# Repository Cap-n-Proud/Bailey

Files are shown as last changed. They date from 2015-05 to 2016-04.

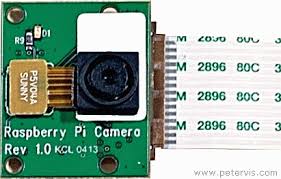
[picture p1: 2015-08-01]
hardware/Img/images.jpg

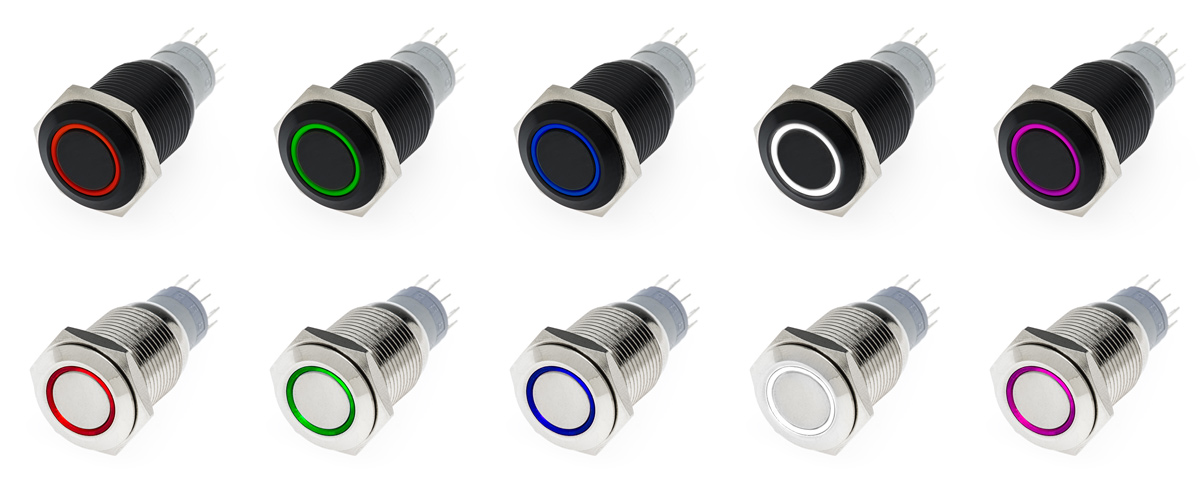
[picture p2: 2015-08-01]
hardware/Img/led-push-button-switch-color-options-pb-x-spdt-x.jpg

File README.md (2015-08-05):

Bailey
======

Areas of research:
1. AI: neural networks and SPO to improve stability
2. Computer vision potentially with neural network
3. Odometry
4. 
To log a warning when anrduino receives an unkown command
see why it makes "waves" when advancing forward
verify bug when hit refresh button robot stalls... (maybre because of long delay in passing telemetry headers?
change PID config only when needd to save time

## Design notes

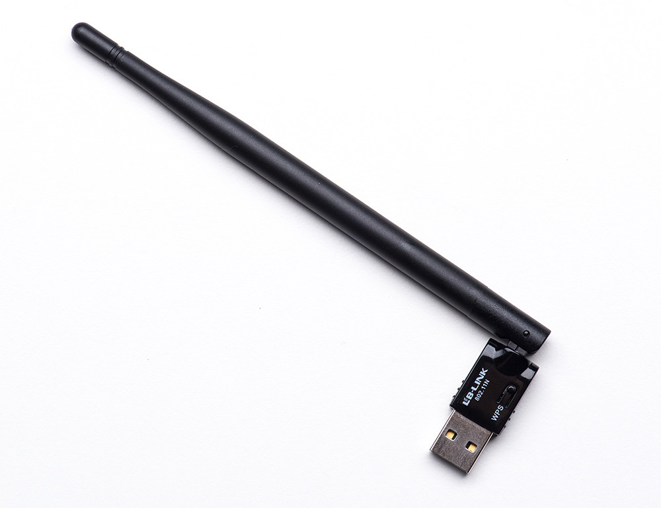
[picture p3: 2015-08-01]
hardware/Img/lrg_wifi_antenna_1.jpeg

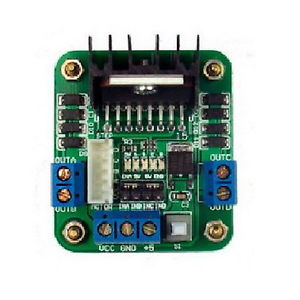
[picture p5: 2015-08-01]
hardware/Img/$_35.JPG

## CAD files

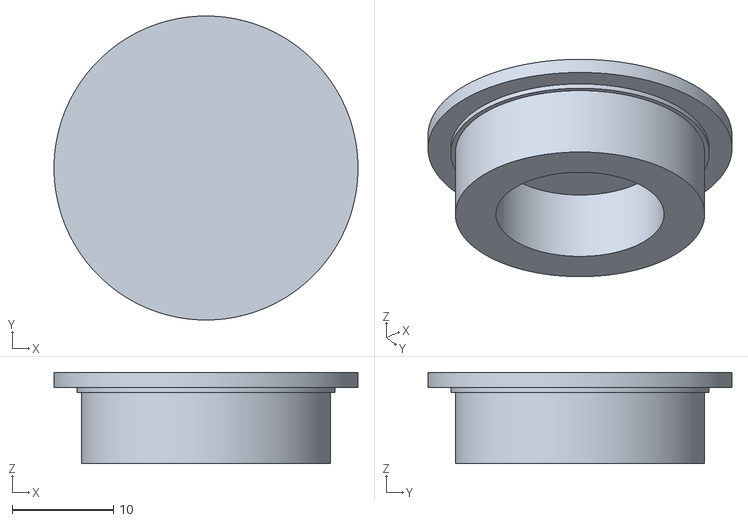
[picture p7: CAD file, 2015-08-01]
hardware/SupportNOservo.stl
30.0 x 30.0 x 9.00

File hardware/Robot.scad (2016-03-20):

//Make passage for cables larger
RobotY = 220;
RobotX = 80;
RobotZ = 5;
BodyHoleR = 20;
BodyHoleSpace = 55;

plateX = 150;
plateZ = 3;
plateY = RobotX;
cablePassageWidht = 8;
plateanchorX = RobotZ;
plateanchorY = 15;
holeradius = 3;
holespace = 3 * holeradius;
borderZ = 30;
border = 8;
T = 0.3;
$fs = 0.01;

stepperSupportHeight = 70;

border = holespace + ((plateX) / holespace - floor((plateX) / holespace)) / 2;
include < TextGenerator.scad > ;

module put_pilogo(mt) {
    fn = "raspberrypi_logo.dxf";
    // calculate the scale and which offset to use

    linear_extrude(height = mt) import (file = fn, scale = scx);
}


module put_Alogo(mt) {
    fn = "arduino.dxf";
    // calculate the scale and which offset to use

    linear_extrude(height = mt) import (file = fn, scale = scx);
}

module put_OAlogo(mt) {
    fn = "ohw-logo.dxf";
    // calculate the scale and which offset to use    
    linear_extrude(height = mt) import (file = fn, scale = scx);
}


module SUB_batteryAnchor() {

}

module arduinoLogo(h, r) {

    scale([0.9, .7, 1]) union() {
        difference() {
            cylinder(h = h, r = r);
            cylinder(h = h, r = r - .25 * r);
        }
        translate([1.8 * r, 0, 0]) difference() {
            cylinder(h = h, r = r);
            cylinder(h = h, r = r - .25 * r);
        }

    }
    translate([0, 0, h / 2]) cube([0.6 * r, 0.2 * r, h], center = true);
    translate([2 * r - 0.4 * r, 0, h / 2]) {
        cube([0.6 * r, 0.2 * r, h], center = true);
        rotate([0, 0, 90]) cube([0.6 * r, 0.2 * r, h], center = true);
    }
}

module plate(plateX, plateY, plateZ, borderZ, holes, baseF, baseB, text) {
    difference() {
        linear_extrude(plateZ, center = true, convexity = 0, twist = 0)

        difference() {

            union() {
                square([plateX, plateY], center = true);

                translate([-plateX / 2 - plateanchorX, plateanchorY + RobotX / 8 - (7 * (RobotX / 8) - plateanchorY), 0]) square([plateanchorX, plateanchorY], center = "True");

                mirror([0, 1, 0]) translate([-plateX / 2 - plateanchorX, plateanchorY + RobotX / 8 - (7 * (RobotX / 8) - plateanchorY), 0]) square([plateanchorX, plateanchorY], center = "True");


                translate([+plateX / 2, plateanchorY + RobotX / 8 - (7 * (RobotX / 8) - plateanchorY), 0]) square([plateanchorX, plateanchorY], center = "True");
                mirror([0, 1, 0]) translate([+plateX / 2, plateanchorY + RobotX / 8 - (7 * (RobotX / 8) - plateanchorY), 0]) square([plateanchorX, plateanchorY], center = "True");

            }

            //punchholes at the bottom of the plate
            if (holes == "True") {
                for (j = [border: holespace: plateY - border]) {
                    for (i = [border: holespace: plateX - 2 * border]) {
                        translate([i + border - plateX / 2 - holeradius / 2, j - plateY / 2, 0]) circle(holeradius);
                    }
                }

            }
        }

        //Passage for cables
        translate([-plateX / 2 + cablePassageWidht, j + border - plateY / 2, 0]) cube([cablePassageWidht, 0.5 * plateY, plateZ], center = true);
        translate([plateX / 2 - cablePassageWidht, j + border - plateY / 2, 0]) cube([cablePassageWidht, 0.5 * plateY, plateZ], center = true);

    }
    if (baseF == "True")
        translate([-plateX / 2, plateY / 2 - plateZ, -plateZ / 2]) cube([plateX, plateZ, borderZ]);
    if (baseB == "True")
        translate([-plateX / 2, -plateY / 2, -plateZ / 2]) cube([plateX, plateZ, borderZ]);

    translate([-plateX / 2, -plateY / 2, 5]) rotate(90, [1, 0, 0]) scale([2, 2, 1]) drawtext(text);

}

module SensorsPlate() {
    IRLedD = 3;

    plate(plateX, plateY, plateZ, borderZ, "True", "True", "false", "");
    difference() {
        translate([0, -plateY / 2 + 10, borderZ - plateZ / 2])
        rotate([180, 0, 0]) difference() {
                scale(v = [1, 0.30, 1]) difference() {
                    cylinder(r = plateX / 2, h = borderZ, center = false);
                    cylinder(r = plateX / 2 - 2 * plateZ, h = borderZ, center = false);
                }


                translate([-plateX / 2, -plateY / 2 + 10, 0]) cube([plateX, 0.35 * plateX / 2, plateY / 2]);
            }
            //hole for the IR sensor
        translate([-plateX / 2 + 12, -plateY / 2 + 2, borderZ / 4]) rotate([100, 0, -30]) translate([6, -3.48, 0]) cube([6, 6.95, 10]);
        translate([-8, -plateY / 2 - 10, borderZ / 4]) rotate([100, 0, 0]) translate([6, -3.48, 0]) cube([6, 6.95, 10]);
        translate([+plateX / 2 - 12, -plateY / 2 + 2, borderZ / 4]) rotate([100, 0, 30]) translate([-12, -3.48, 0]) cube([6, 6.95, 10]);

        //holes for sonars and slots for sensors
        translate([0 + 28, -plateY / 2 - 8, borderZ / 2]) rotate([90, 0, 0]) cylinder(r = 16.8 / 2, h = 8);
        translate([0 - 28, -plateY / 2 - 8, borderZ / 2]) rotate([90, 0, 0]) cylinder(r = 16.8 / 2, h = 8);
        translate([0, -plateY / 2 - 8, borderZ / 2]) rotate([90, 0, 0]) cube([3, 1, 5]);
        translate([-plateX / 2 + 12, -plateY / 2 + 2, borderZ / 2]) rotate([90, 0, -30]) cube([3, 1, 5]);
        translate([+plateX / 2 - 12, -plateY / 2 + 2, borderZ / 2]) rotate([90, 0, 30]) cube([3, 1, 5]);

        translate([-plateX / 2 + 12, -plateY / 2 + 2, borderZ / 4]) rotate([100, 0, -30]) cylinder(r = 1.5 + IRLedD, h = 10);
        translate([-8, -plateY / 2 - 10, borderZ / 4]) rotate([100, 0, 0]) cylinder(r = 1.5 + IRLedD, h = 10);
        translate([+plateX / 2 - 12, -plateY / 2 + 2, borderZ / 4]) rotate([100, 0, 30]) cylinder(r = 1.5 + IRLedD, h = 10);
    }

    //Tubes to focus the IR beams
    translate([-plateX / 2, -plateY / 2 - 30, 0]) difference() {
        cylinder(r = 1 + IRLedD, h = 15);
        cylinder(r = IRLedD, h = 15);
    }
    translate([-plateX / 2 + 15, -plateY / 2 - 30, 0]) difference() {
        cylinder(r = 1 + IRLedD, h = 15);
        cylinder(r = IRLedD, h = 15);
    }
    translate([-plateX / 2 + 30, -plateY / 2 - 30, 0]) difference() {
            cylinder(r = 1 + IRLedD, h = 15);
            cylinder(r = IRLedD, h = 15);
        }
        //	translate([-8,-plateY/2-10,borderZ/4]) rotate([100,0,0])difference (){cylinder(r=1.2*IRLedD,h=8); cylinder(r=IRLedD,h=10);}
        //	translate([+plateX/2-12,-plateY/2+2,borderZ/4]) rotate([100,0,30])difference (){cylinder(r=1.2*IRLedD,h=10); cylinder(r=IRLedD,h=8);}
}

module Powerplate() {

    difference() {
        plate(plateX, plateY, plateZ, borderZ, "True", "True", "True", "Power");
        //fix for batteries
        translate([plateX / 2 - 15, plateY / 2 + 5, borderZ / 2]) translate([0, 0, 3]) rotate([90, 0, 0]) cylinder(h = 10, r = 2);
        translate([-plateX / 2 + 15, plateY / 2 + 5, borderZ / 2]) translate([0, 0, 3]) rotate([90, 0, 0]) cylinder(h = 10, r = 2);
        translate([plateX / 2 - 15, -plateY / 2 + 5, borderZ / 2]) translate([0, 0, 3]) rotate([90, 0, 0]) cylinder(h = 10, r = 2);
        translate([-plateX / 2 + 15, -plateY / 2 + 5, borderZ / 2]) translate([0, 0, 3]) rotate([90, 0, 0]) cylinder(h = 10, r = 2);

    }

    translate([plateX / 2 - 15, plateY / 2 + 4, borderZ / 2])
    difference() {
        sphere(2);
        rotate([0, 90, 0]) translate([0.7, 0.6, 0]) cylinder(h = 10, r = 1.1, center = true);
    }
    translate([-plateX / 2 + 15, plateY / 2 + 4, borderZ / 2])
    difference() {
        sphere(2);
        rotate([0, 90, 0]) translate([0.7, 0.6, 0]) cylinder(h = 10, r = 1.1, center = true);
    }
    translate([plateX / 2 - 15, -plateY / 2 - 1, borderZ / 2]) rotate([0, 0, 180])
    difference() {
        sphere(2);
        rotate([0, 90, 0]) translate([0.7, 0.6, 0]) cylinder(h = 10, r = 1.1, center = true);
    }
    translate([-plateX / 2 + 15, -plateY / 2 - 1, borderZ / 2]) rotate([0, 0, 180])
    difference() {
        sphere(2);
        rotate([0, 90, 0]) translate([0.7, 0.6, 0]) cylinder(h = 10, r = 1.1, center = true);
    }


    //mid section
    difference() {
        translate([-plateX / 2, 0, 0]) cube([plateX, plateZ, borderZ]);
        for (i = [1: plateX / 4: plateX]) {
            translate([i + (-plateX / 2) + borderZ / 2, 10, borderZ / 2]) rotate([90, 0, 0]) cylinder(20, r = 0.8 * borderZ / 2);

        }


    }


}

module BrainPlate() {
    plate(plateX, plateY, plateZ, borderZ, "False", "True", "True", "");
    translate([-plateX / 2, -plateY / 2, borderZ / 2]) {
        color("green") rotate([90, 0, 0])
        translate([120, -2, 0]) scale(0.3) arduinoLogo(5, 30);
        translate([5, -12, 0]) scale(0.1) put_pilogo(1.5 / 0.1);
        translate([80, -2, 0]) scale(0.1) put_OAlogo(1.5 / 0.1);
    }
}
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

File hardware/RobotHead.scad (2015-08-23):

//Increase shell thickness
//Change slot for Raspberry 
//Change slot for camera (no need of pan

PIcameraDiam = 8;
PIcameraX = 25;
PIcameraY = 25;
// Raspberry Pi dimensions 85.60mm x 56mm x 21mm 
widht = 148;
depth = 120;
border = widht * 0.2;
T = 6;
2DOF_L = 40;
2DOF_H = 45;
USBH = 20;
USBL = 50 + 6;
FN = 50;
CameraModulePos = [0, 70, 20];
Tolerance= 0.5;
HSupportHoleDiam = 25;

$fn = 150;

//$fs = 0.01; // change me to 0.5 when doing final render for export

phi = 1.618033988749894848204586834;

//-----------------------------------
module HeadShell() {
	difference() {
		resize([widht + border, depth, depth]) sphere(1);
		//Create the inner shell
		resize([widht + border - T, depth - T, depth - T]) sphere(1);
	}
	//Endcaps
	intersection() {
		resize([widht + border, depth, depth ]) sphere(1);
		translate([widht / 2 - 3 / 2, 0, 0]) cube([3, 100, 100], center = true);

	}
	intersection() {
		resize([widht + border, depth, depth]) sphere(1);
		translate([-widht / 2 + 3 / 2, 0, 0]) cube([3, 100, 100], center = true);

	}
}
module H() {
	difference() {
		HeadShell();
		//2DOF slot
		translate(CameraModulePos) rotate([100, 0, 0]) resize([2DOF_L, 2DOF_H, 50]) cylinder(h = 30, r = 100);

		//Two cubes to cut the ends of the head
		translate([widht / 2, -widht / 2, -widht / 2]) cube(widht);
		translate([-3 / 2 * widht, -widht / 2, -widht / 2]) cube(widht);
		//Lower cut
		translate([-widht / 2, -widht / 2, -(widht + 40)]) cube(widht);
		//Holes for buttons
		translate([-widht / 4, -depth / 4, widht / 4]) rotate([45, 30, -45]) ButtonHoleL();
		translate([+widht / 4, -depth / 4, widht / 4]) rotate([45, 30, 0]) ButtonHoleL();

		//Raspberrry slot
		translate([-USBL / 2, -depth / 2, -10]) cube([USBL, 20, USBH]);
 
        translate([-1.1*USBL / 2, -depth / 2, -10]) cube([1.1*USBL, 20, 3 ]);
		//Simulates Raspberry PI dimensions
		//translate([-USBL/2+56,-depth/2,-10])rotate([0,0,90])cube([85.60,56,21]);
        
        //Hole for RGB LED
        translate([0, 0, depth/2]) rotate([0, 0, 0]) cylinder(h=10,r=5/2-Tolerance, center=true);
        
        //Hole for anchoring
		translate([widht / 2, 0, 0]) rotate([90, 180, 90]) cylinder(h=10,r=HSupportHoleDiam/2, center=true);
		//Microserv slot
        translate([-widht / 2 - 10, 0, 0]) rotate([90, 180, 90]) translate([-5.9 - 4.7 / 2, 0, 0]) microservo();

	}
    
    //This is the support fo  rthe raspberry slot
     intersection(){
            HeadShell();
            for (z = [-USBL/2: 2: USBL/2]) 
            {
                translate([z, -depth/2+1, 0])
                cube([0.4,20,USBH], center = true);
            }
            }
		
}
//-----------------------------------

module camera_supportOLD()

{
	translate(CameraModulePos - [0, +5, +6] - [0, 0, T + 12]) rotate([0, 0, 00]) box(13, 24.5, 17, 3);
	difference() {
		translate(CameraModulePos - [0, 0, T + 12]) box(2DOF_L + 2 * T, 2DOF_H, 30, T);

		difference() {
			translate(CameraModulePos - [0, 0, T + 12]) box(2DOF_L + 2 * T, 2DOF_H, 30, T);
			resize([widht + border - T, depth - T, depth - T]) sphere(1, $fn = FN);

		}
	}

}
//-----------------------------------

module box(Xdim, Ydim, Zdim, thickness)
//Creates a box, dimensions are internal
{
	difference() {
		//translate([10,0,-thickness])
		cube([Xdim + thickness, Ydim + thickness, Zdim], center = true);
		translate([0, 0, thickness / 2]) cube([Xdim, Ydim, Zdim], center = true);

		translate([-Xdim / 2, 0, -0.5 * Zdim]) cube([5, Ydim + 2 * thickness, Zdim / 2 + thickness], center = true);
		translate([+Xdim / 2, 0, -0.5 * Zdim]) cube([5, Ydim + 2 * thickness, Zdim / 2 + thickness], center = true);
		translate([+Xdim / 2, 0, 0]) cube([thickness / 2, 0.3 * Ydim, Zdim], center = true);
		translate([-Xdim / 2, 0, 0]) cube([thickness / 2, 0.3 * Ydim, Zdim], center = true);

	}
}

module support() {
	difference() {

		linear_extrude(height = 4, center = true, convexity = 10, twist = 0) polygon(points = [
			[0, 0],
			[0, 16],
			[4, 16]
		]);
		translate([2, 18, 0]) rotate([90, 0, 0]) cylinder(h = 15, d = 1.5);
		translate([0.5, 10, -6]) cube([4, 2, 12], center = false);
	}
}


//-----------------------------------

module CS()
translate(CameraModulePos + [6.25, -25, -32]) {
	box(24.5, 13, 17, T);
	translate([0, 12, 0]) cube([24.5 + T, 5 + T, 17], center = true);
}
//-----------------------------------



module camera_support()

{

	difference() {
		CS();

		difference() {
			CS();
			resize([widht + border - T, depth - T, depth - T]) sphere(1);

		}
	}

}

module ButtonHoleL() {

	cylinder(h = 20, r = 8);
}


module TiltServo() {
	//translate([widht/2-10,0,0])rotate([90,90,90])translate([-35.1,0,0])TiltServo();
	translate([0, -5, 0]) cylinder(h = 20, r = 2.5);
	translate([0, 5, 0]) cylinder(h = 20, r = 2.5);

	translate([50.5, -5, 0]) cylinder(h = 20, r = 2.5);
	translate([50.5, 5, 0]) cylinder(h = 20, r = 2.5);

	translate([35.1, 0, 0]) cylinder(h = 40, r = 5);
	translate([35.1, 0, 0]) cylinder(h = 20, r = 5);

	translate([5, -10.5, 0]) cube([41.50, 21, 20], center = false);
}






module SUB_bearing() {
	cylinder(h = 0.5, r = 25.5 / 2);
	translate([0, 0, 0.5]) cylinder(h = 1.5, r = 30 / 2);
}

module bearingServo() {
	difference() {
		SUB_bearing();
		cylinder(h = 5, r = 2);
	}
}

module bearingNoServo() {
	union() {
		SUB_bearing();
        
		translate([0,0,-8/2])difference(){
            cylinder(h = 12, r = HSupportHoleDiam/2-Tolerance, center=true);
            cylinder(h = 12, r = HSupportHoleDiam/2-Tolerance-4, center=true);
        }
	}
}



module microservo() {

	translate([0, 0, 0]) cylinder(h = 20, r = 1.2);
	translate([27.2, 0, 0]) cylinder(h = 20, r = 1.2);

	translate([5.9 + 4.7 / 2 + 6, 0, 0]) cylinder(h = 40, r = 7 / 2);

	translate([5.9 + 4.7 / 2, 0, 0]) cylinder(h = 40, r = 7);
}

/*difference(){
translate([-5,-10,-0])cube([40,20,2]);
microservo();
}*/


//camera_support();

/*difference(){
translate([-5,-10,0])cube([35,20,1], center=false);
microservo();
}*/

module PiSupport() {
	difference() {

		translate([-USBL / 2, -widht / 2, -USBH / 2 - 5]) cube([USBL, widht, 5]);
		translate([0, 0, -USBH / 2 - 2.5]) cube([USBL - 20, 100, 5], center = true);

		difference() {
			translate([-USBL / 2, -widht / 2, -USBH / 2 - 5]) cube([USBL, widht, 5]);
			resize([widht + border - T, depth - T, depth - T]) sphere(1);
		}
    translate([(USBL - 20)/2+10/2+2.75/2,-widht / 2 +85-58-3,-USBH / 2 -2]){
translate([0, +85-58, -2])cylinder(r=2.75/2-Tolerance, h=10, center=true);
translate([0, +85-58+58, -2])cylinder(r=2.75/2-Tolerance, h=10, center=true);
translate([0-49, +85-58, -2])cylinder(r=2.75/2-Tolerance, h=10, center=true);
translate([0-49, +85-58+58, -2])cylinder(r=2.75/2-Tolerance, h=10, center=true);
}
	}

}




//PiSupport();
//bearingServo();
//bearingNoServo();
 /*               translate([-1, 0, -5])
  cube([USBL,20,2], center = true);
for (z = [-USBL/2: 3: USBL/2]) 
            {
                translate([z, 0, 0])
                cube([0.6,20,10], center = true);
            }
   */


module SUB_PiCamHoles(T) {
// T is the tolerance for holes
        translate([PIcameraX/2-2, 0, PIcameraY/2-2])rotate([90,0,0])cylinder(r=1+T,h=10, center=true);
		translate([-(PIcameraX/2-2), 0, PIcameraY/2-2])rotate([90,0,0])cylinder(r=1+T,h=10, center=true);
		translate([PIcameraX/2-2, 0, (PIcameraY/2-2)-12.5])rotate([90,0,0])cylinder(r=1+T,h=10, center=true);
		translate([-(PIcameraX/2-2), 0, (PIcameraY/2-2)-12.5])rotate([90,0,0])cylinder(r=1+T,h=10, center=true); 
    
}    

module eye(){
resize([widht/4+10,0,+depth/4+15])
intersection()
{
difference() {
		HeadShell();
        
    }

translate(CameraModulePos) rotate([100, 0, 0]) resize([2DOF_L, 2DOF_H, 50]) cylinder(h = 30, r = 100);
}

//difference()

{
intersection()
{
difference() {
		resize([widht + border, depth, depth]) sphere(1);
		//Create the inner shell
		resize([widht + border , depth -20, depth - 20]) sphere(1);
        
    }

translate(CameraModulePos) rotate([100, 0, 0]) resize([2DOF_L, 2DOF_H, 50]) cylinder(h = 30, r = 100);
}
}


}
module PICam()
{
    
{
translate([0,-12,0])cube([PIcameraX + Tolerance, 20, PIcameraY + Tolerance], center = true);
translate([0, 0, -2.5]) 
rotate([90, 0, 0]) cube([PIcameraDiam + Tolerance, 10, PIcameraDiam + Tolerance], center = true);
    translate([0,-12,-PIcameraY/2])cube([PIcameraX - 5, 20, 8], center = true);
//		translate([0,0.9*R,0])
SUB_PiCamHoles(0.3);
}
}

/*difference()
{
eye();
translate([0,widht/4+20,15])rotate([12,0,0])PICam();
}
*/
//PICam();
bearingNoServo();

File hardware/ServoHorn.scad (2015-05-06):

/**
 *  Parametric servo arm generator for OpenScad
 *  Générateur de palonnier de servo pour OpenScad
 *
 *  Copyright (c) 2012 Charles Rincheval.  All rights reserved.
 *
 *  This library is free software; you can redistribute it and/or
 *  modify it under the terms of the GNU Lesser General Public
 *  License as published by the Free Software Foundation; either
 *  version 2.1 of the License, or (at your option) any later version.
 *
 *  This library is distributed in the hope that it will be useful,
 *  but WITHOUT ANY WARRANTY; without even the implied warranty of
 *  MERCHANTABILITY or FITNESS FOR A PARTICULAR PURPOSE.  See the GNU
 *  Lesser General Public License for more details.
 *
 *  You should have received a copy of the GNU Lesser General Public
 *  License along with this library; if not, write to the Free Software
 *  Foundation, Inc., 51 Franklin St, Fifth Floor, Boston, MA  02110-1301  USA
 *
 *  Last update :
 *  https://github.com/hugokernel/OpenSCAD_ServoArms
 *
 *  http://www.digitalspirit.org/
 */

$fn = 40;

/**
 *  Clear between arm head and servo head
 *  With PLA material, use clear : 0.3, for ABS, use 0.2
 */
SERVO_HEAD_CLEAR = 0.3;
arm_screw_diameter = 5;
arm_thickness = 5;
/**
 *  Head / Tooth parameters
 *  Futaba 3F Standard Spline
 *  http://www.servocity.com/html/futaba_servo_splines.html
 *
 *  First array (head related) :
 *  0. Head external diameter
 *  1. Head heigth
 *  2. Head thickness
 *  3. Head screw diameter
 *
 *  Second array (tooth related) :
 *  0. Tooth count
 *  1. Tooth height
 *  2. Tooth length
 *  3. Tooth width
 */
FUTABA_3F_SPLINE = [
    [5.92, 8, 1.1, 2.5],
    [25, 0.3, 0.7, 0.1]
];

module servo_futaba_3f(length, count) {
    servo_arm(FUTABA_3F_SPLINE, [length, count]);
}

/**
 *  If you want to support a new servo, juste add a new spline definition array
 *  and a module named like servo_XXX_YYY where XXX is servo brand and YYY is the
 *  connection type (3f) or the servo type (s3003)
 */

module servo_standard(length, count) {
    servo_futaba_3f(length, count);
}

/**
 *  Tooth
 *
 *    |<-w->|
 *    |_____|___
 *    /     \  ^h
 *  _/       \_v
 *   |<--l-->|
 *
 *  - tooth length (l)
 *  - tooth width (w)
 *  - tooth height (h)
 *  - height
 *
 */
module servo_head_tooth(length, width, height, head_height) {
    linear_extrude(height = head_height) {
        polygon([[-length / 2, 0], [-width / 2, height], [width / 2, height], [length / 2,0]]);
    }
}

/**
 *  Servo head
 */
module servo_head(params, clear = SERVO_HEAD_CLEAR) {

    head = params[0];
    tooth = params[1];

    head_diameter = head[0];
    head_heigth = head[1];

    tooth_count = tooth[0];
    tooth_height = tooth[1];
    tooth_length = tooth[2];
    tooth_width = tooth[3];

    % cylinder(r = head_diameter / 2, h = head_heigth + 1);

    cylinder(r = head_diameter / 2 - tooth_height + 0.03 + clear, h = head_heigth);

    for (i = [0 : tooth_count]) {
        rotate([0, 0, i * (360 / tooth_count)]) {
            translate([0, head_diameter / 2 - tooth_height + clear, 0]) {
                servo_head_tooth(tooth_length, tooth_width, tooth_height, head_heigth);
            }
        }
    }
}

/**
 *  Servo hold
 *  - Head / Tooth parameters
 *  - Arms params (length and count)
 */
module servo_arm(params, arms) {

    head = params[0];
    tooth = params[1];

    head_diameter = head[0];
    head_heigth = head[1];
    head_thickness = head[2];
    head_screw_diameter = head[3];

    tooth_length = tooth[2];
    tooth_width = tooth[3];

    arm_length = arms[0];
    arm_count = arms[1];

    /**
     *  Servo arm
     *  - length is from center to last hole
     */
    module arm(tooth_length, tooth_width, head_height, head_heigth, hole_count = 1) {

        //arm_screw_diameter = 5;

        difference() {
            union() {
                cylinder(r = tooth_width / 2, h = head_heigth);

                linear_extrude(height = head_heigth) {
                    polygon([
                        [-tooth_width / 2, 0], [-tooth_width / 3, tooth_length],
                        [tooth_width / 3, tooth_length], [tooth_width / 2, 0]
                    ]);
                }

                translate([0, tooth_length, 0]) {
                    cylinder(r = tooth_width / 3, h = head_heigth);
                }

                if (tooth_length >= 12) {
                    translate([-head_heigth / 2 + 2, 3.8, -4]) {
                        rotate([90, 0, 0]) {
                            rotate([0, -90, 0])
											//Support for the center hole
										 {
                                linear_extrude(height = head_heigth) {
                                    polygon([
                                        [-tooth_length / 2.5, 4], [0, 4], [0, - head_height + 5],
                                        [-2, - head_height + 5]
                                    ]);
                                }
                            }
                        }
                    }
                }
            }

            // Hole
            for (i = [0 : hole_count - 1]) {
                //translate([0, length - (length / hole_count * i), -1]) {
                translate([0, tooth_length - (4 * i), -1]) {
                    cylinder(r = arm_screw_diameter / 2, h = 10);
                }
            }

            cylinder(r = head_screw_diameter / 2, h = 10);
        }
    }

    difference() {
        translate([0, 0, 0.1]) {
            cylinder(r = head_diameter / 2 + head_thickness, h = head_heigth + 1);
        }

        cylinder(r = head_screw_diameter / 2, h = 10);

        servo_head(params);
    }

    //arm_thickness = head_thickness;

    // Arm
    translate([0, 0, head_heigth]) {
        for (i = [0 : arm_count - 1]) {
            rotate([0, 0, i * (360 / arm_count)]) {
                arm(arm_length, head_diameter + arm_thickness * 2, head_heigth, 2);
            }
        }
    }
}

module demo() {
    rotate([0, 180, 0])
        servo_standard(23, 4);
}

demo();

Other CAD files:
hardware/Wheel.scad
hardware/TextGenerator.scad
hardware/Washer.scad
hardware/power.scad

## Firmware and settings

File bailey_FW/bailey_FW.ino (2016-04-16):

// Check this out https://github.com/adafruit/AccelStepper.git
// https://www.pjrc.com/teensy/td_libs_AccelStepper.html
//http://42bots.com/tutorials/bipolar-stepper-motor-control-with-arduino-and-an-h-bridge/
//------------------ Libraries ------------------


//#define DEBUG

#include "FreeIMU.h"
#include <Wire.h>
#include <SPI.h>
#include <I2Cdev.h>
#include <MPU60X0.h>
#define M_PI 3.14159265358979323846f
#include <MS561101BA.h>
#include <HMC58X3.h>
#include <Wire.h> // for i2c
#include <PID_v1.h> // https://github.com/br3ttb/Arduino-PID-Library.git
#include <TimedAction.h> // for updating sensors and debug http://bit.ly/pATDBi http://playground.arduino.cc/Code/TimedAction
#include <EEPROM.h> // for storing configuraion
//#include <avr/wdt.h> // watchdog http://savannah.nongnu.org/projects/avr-libc/
//#include <KalmanFilter.h> // github.com/nut-code-monkey/KalmanFilter-for-Arduino
// Try also: https://github.com/TKJElectronics/KalmanFilter.git
#include <AccelStepper.h> //https://github.com/adafruit/AccelStepper.git

#define SERIALCOMMAND_HARDWAREONLY 1
#include <SerialCommand.h> // https://github.com/kroimon/Arduino-SerialCommand.git


//------------------ Constants ------------------
#define TO_RAD(x) (x * 0.01745329252)  // *pi/180
#define TO_DEG(x) (x * 57.2957795131)  // *180/pi
#define speedMultiplier 1
#define SERIAL_BAUD 38400
#define CONFIG_START 32 //EEPROM address to start the config

/* Configutation parameters */
struct Configuration {
  String FirmwareVersion;

  double speedPIDKp;
  double speedPIDKi;
  double speedPIDKd;
  double speedPIDMoveFactor;
  double speedPIDOutputLowerLimit;
  double speedPIDOutputHigherLimit;
  double anglePIDAggKp;
  double anglePIDAggKi;
  double anglePIDAggKd;
  double anglePIDConKp;
  double anglePIDConKi;
  double anglePIDConKd;
  double anglePIDOutputLowerLimit;
  double anglePIDOutputHigherLimit;
  double TriggerAngleAggressive;
  double calibratedZeroAngle;
  uint8_t anglePIDSampling;
  uint8_t speedPIDSampling;

  double angleKalmanFilterR;
  uint8_t angleSensorSampling;
  uint8_t motorSpeedSensorSampling;
  double speedKalmanFilterR;

  int MotorLeftENABLEA;
  int MotorLeftIN1;
  int MotorLeftIN2;
  int MotorRightENABLEA;
  int MotorRightIN1;
  int MotorRightIN2;
  int leftEncoder1;
  int leftEncoder2;
  int rightEncoder1;
  int rightEncoder2;

  double steerGain;
  double throttleGain;
  double Maxsteer;
  double Maxthrottle;
  uint8_t motorLeftMinimumSpeed;
  uint8_t motorRightMinimumSpeed;
  int motorsON;

  int numParticles;
  double maxInteractions;
  int SPOConfigEval;
  boolean debugSPO;
  double SPOspread = 0.10;

  int commandDelay;
  //int speakerPin;

  boolean debug;
  uint8_t debugLevel;
  uint8_t debugSampleRate;
  uint8_t speedPIDOutputDebug;
  uint8_t speedPIDInputDebug;
  uint8_t speedKalmanFilterDebug;
  uint8_t speedRawDebug;
  uint8_t speedMovingAvarageFilter2Debug;
  uint8_t anglePIDSetpointDebug;
  uint8_t anglePIDInputDebug;
  uint8_t anglePIDOutputDebug;
  uint8_t angleRawDebug;
  uint8_t  activePIDTuningDebug;
};
Configuration configuration;
byte b[sizeof(Configuration)];

double UserControl[1]; //Steer, Throttle
// float Thr = 0; //CHECK IF NEEDED

void setConfiguration(boolean force) {
  /* Flash is erased every time new code is uploaded. Write the default configuration to flash if first time */
  // running for the first time?
  uint8_t codeRunningForTheFirstTime = EEPROM.read(CONFIG_START); // flash bytes will be 255 at first run
  if (codeRunningForTheFirstTime || force) {
    if (configuration.debug) {
      Serial.print("No config found, defaulting ");
    }
    /* First time running, set defaults */
    configuration.FirmwareVersion = "1.2";
    configuration.speedPIDOutputLowerLimit = -10.00; //Default was -5
    configuration.speedPIDOutputHigherLimit = 10.00;

    configuration.anglePIDConKp = 8.80;
    configuration.anglePIDConKi = 2.21;
    configuration.anglePIDConKd = 0.975;
    configuration.speedPIDMoveFactor = 0.7;

    configuration.anglePIDAggKp = 12.70;
    configuration.anglePIDAggKi = 3.5;
    configuration.anglePIDAggKd = 1.951;

    configuration.speedPIDKp = 0.3854;
    configuration.speedPIDKi = 0.1374;
    configuration.speedPIDKd = 0.00245;
    configuration.anglePIDOutputLowerLimit = -100;
    configuration.anglePIDOutputHigherLimit = 100;

    configuration.MotorLeftENABLEA = 8;
    configuration.MotorLeftIN1 = 9;
    configuration.MotorLeftIN2 = 10;
    configuration.MotorRightENABLEA = 11;
    configuration.MotorRightIN1 = 12;
    configuration.MotorRightIN2 = 13;
    configuration.leftEncoder1 = 2;
    configuration.leftEncoder2 = 4;
    configuration.rightEncoder1 = 3;
    configuration.rightEncoder2 = 5;

    configuration.motorLeftMinimumSpeed = 55;//40;
    configuration.motorRightMinimumSpeed = 58;//44;
    configuration.steerGain = 1;
    configuration.throttleGain = 1;
    configuration.Maxsteer = 20; //Max allowed percentage difference. Up to the remote to provide the right scale.
    configuration.Maxthrottle = 6; //Max speed expressed in inclination degrees. Up to the remote to provide the right scale.

    configuration.motorsON = 0;
    configuration.debug = 0;

    configuration.TriggerAngleAggressive = 3.50;
    configuration.calibratedZeroAngle = 1.8;

    configuration.anglePIDSampling = 10;
    configuration.speedPIDSampling = 10;

    configuration.angleKalmanFilterR = 10.00;
    configuration.angleSensorSampling = 5;
    configuration.motorSpeedSensorSampling = 5;
    configuration.speedKalmanFilterR = 20.00;

    configuration.maxInteractions = 30;
    configuration.numParticles = 20;
    configuration.SPOConfigEval = 2000;
    configuration.debugSPO = false;
    //Define a percentage around the known stable values
    configuration.SPOspread = 0.10;

    configuration.commandDelay = 5;
    configuration.debugLevel = 0;
    configuration.debugSampleRate = 1000;
    //  configuration.speedPIDSetpointDebug = 1;
    configuration.speedPIDOutputDebug = 1;
    configuration.speedPIDInputDebug = 1;
    configuration.speedKalmanFilterDebug = 1;
    configuration.speedRawDebug = 1;
    configuration.speedMovingAvarageFilter2Debug = 0;
    configuration.anglePIDSetpointDebug = 1;
    configuration.anglePIDInputDebug = 1;
    configuration.anglePIDOutputDebug = 1;
    configuration.angleRawDebug = 1;
    configuration.activePIDTuningDebug = 1;
    //configuration.speakerPin = 13;

    saveConfig();
    delay(100);
  }
  else {
    if (configuration.debug)
      Serial.println("Config found");
    loadConfig();
  }
};

//------------------ Definitions MOTORS ------------------

//------------------ Definitions IMU  ------------------
String SEPARATOR = ","; //Used as separator for telemetry
float ypr[3];
float altimeter; // yaw pitch roll
float imuValues[6];
float pitch, roll, yaw, prev_pitch, prev_yaw, prev_roll;
float pitchd1, pitchd2;


// Set the FreeIMU object
FreeIMU my3IMU = FreeIMU();

float speedKalmanFiltered = 0;
float speedFIRFiltered = 0;
float dISTEKalmanFiltered = 0;

SerialCommand SCmd;   // The SerialCommand object

long StartL = 0, LoopT = 0, StartL2 = 0, TxLoopTime = 0;

String LastEvent = "";
String PIDConfigType = "";

// PID variables
double anglePIDSetpoint, anglePIDInput, anglePIDOutput;
double speedPIDInput, speedPIDOutput, speedPIDSetpoint;
double anglePIDInputFiltered;
double ISTE = 0, dISTE = 0;
int AUTOTUNE = 0;

// The cascading PIDs. The tunings are updated from the remote
PID anglePID(&anglePIDInput, &anglePIDOutput, &anglePIDSetpoint, 0, 0, 0, DIRECT);
PID speedPID(&speedPIDInput, &speedPIDOutput, &speedPIDSetpoint, 0, 0, 0, DIRECT);

//Init the timers
// These take care of the timing of things
TimedAction debugTimedAction = TimedAction(configuration.debugSampleRate, debugEverything); //Print debug info
//TimedAction updateMotorSpeedTimedAction = TimedAction(100, updateMotorSpeeds); //
//ADD HERE A TIMED ACTIONS FOR SENSORS
//TimedAction remoteControlWatchdogTimedAction = TimedAction(5000, stopRobot);

//Reads serial for commands
TimedAction RemoteReadTimedAction = TimedAction(250, RemoteRead);

//Reads serial for commands
TimedAction ReadIMUTimedAction = TimedAction(100, ReadIMU);

//Upload telemetry data
TimedAction TelemetryTXTimedAction = TimedAction(250, TelemetryTX);



//------------------ Setup ------------------
void setup() {
  //pinMode(configuration.speakerPin, OUTPUT);

  Serial.begin(SERIAL_BAUD);
  delay(50);

  // Load config from eeprom
  setConfiguration(true);
  // init i2c and IMU
  delay(100);
  Wire.begin();

  //Init control systems
  controlConfig();
  // motorsSetup();
  // Filters
  // speedKalmanFilter.setState(0);
  // balanceKalmanFilter.setState(0);
  // dISTEKalmanFilter.setState(0);
  //float coefficients[] = {
  //  1,1,1,1,1,1,1,1,1              };
  //speedMovingAvarageFilter2.setCoefficients(coefficients);
  //speedMovingAvarageFilter2.setNumberOfTaps(9);
  //speedMovingAvarageFilter2.setGain((float) (1/9));

  //Serial.println("IMU...");
  delay(50);
  my3IMU.init(); //init the IMU
  delay(150);



  if (configuration.debug == 1)
    debugConfiguration();

  //saveConfig();
  // set the watchdog to 2s (this will restart the arduino if it freezes)
  //wdt_enable(WDTO_2S);

  // swarnInit();
  LastEvent = "Swarn ready";
  //RemoteInit();

  // Setup callbacks for SerialCommand commands
  SCmd.addCommand("SCMD", setCommand);
  SCmd.addCommand("READ", printCommand);
  //SCmd.addDefaultHandler(unrecognizedCMD);  // Handler for command that isn't matched
  //play(notes, beats);
}

//------------------ Main loop ------------------
void loop() {
  StartL = millis();
  //wdt_reset();
  // update sensors and motors, also chek commands and send back telemetry
  //ADD HERE A TIMED ACTIONS FOR SENSORS
  ReadIMUTimedAction.check();
  RemoteReadTimedAction.check();
  TelemetryTXTimedAction.check();
  //updateMotorSpeedTimedAction.check();
  //updateMotorSpeeds(UserControl[0], UserControl[1]);

  if (AUTOTUNE == 1) {
    //SwarnTimedAction.check();
  }

  // Speed pid,  input is wheel speed, output is angleSetpoint
  speedPIDSetpoint = configuration.Maxthrottle * UserControl[1];
  //If we are moving we need to reduce the Speed PID values in order to avoud "stops and go"
  if (UserControl[1] != 0) {
    speedPID.SetTunings(configuration.speedPIDMoveFactor * configuration.speedPIDKp, configuration.speedPIDMoveFactor * configuration.speedPIDKi, configuration.speedPIDMoveFactor * configuration.speedPIDKd);
  } else {
    speedPID.SetTunings(configuration.speedPIDKp, configuration.speedPIDKi, configuration.speedPIDKd);
  }
  speedPID.Compute();
  anglePIDSetpoint = -speedPIDOutput;

  // Update angle PID tuning
  if (abs(anglePIDInput) < (float) configuration.TriggerAngleAggressive && configuration.TriggerAngleAggressive != 0) {
    //we're close to setpoint, use conservative tuning parameters
    anglePID.SetTunings((float) configuration.anglePIDConKp, (float) configuration.anglePIDConKi, (float) configuration.anglePIDConKd);
    PIDConfigType = "CONSERVATIVE";

  } else if (abs(anglePIDInput) > (float) configuration.TriggerAngleAggressive && abs(anglePIDInput) <= 30) {

    //we're far from setpoint, use aggressive tuning parameters
    anglePID.SetTunings((float) configuration.anglePIDAggKp, (float) configuration.anglePIDAggKi, (float) configuration.anglePIDAggKd);
    PIDConfigType = "AGGRESSIVE";

  } else {
    anglePID.SetTunings(0, 0, 0);
  }

  anglePID.Compute();
  //Filter the angle with Kalman
  //angleKalmanFilter.correct(anglePIDOutput);
  //anglePIDOutput = angleKalmanFilter.getState();

  if (configuration.motorsON == 1) {
    //Serial.println("input sent to motors");

    //motorLeft.setSpeedPercentage(-anglePIDOutput - configuration.steerGain * (UserControl[0])); // + configuration.throttleGain*UserControl[1]);
    //motorRight.setSpeedPercentage(-anglePIDOutput + configuration.steerGain * (UserControl[0])); // + configuration.throttleGain*UserControl[1]);
  } else {
    //motorLeft.setSpeed(0);
    //motorRight.setSpeed(0);
  }
  if (configuration.debug == 1)
    debugTimedAction.check();


  dISTE = (LoopT / 1000 * (anglePIDSetpoint - pitch) * (anglePIDSetpoint - pitch));
  ISTE = ISTE + dISTE;
  LoopT = millis() - StartL;
}



/* just debug functions. uncomment the debug information you want in debugEverything */
void debugEverything() {
  debugImu();
  debugAnglePID();
  debugSpeedPID();
  //debugISE();
  //debugAnglePIDCoeff();
  //debugSpeedPIDCoeff();
  //debugEncoders();
  debugMotorSpeeds();
  //debugMotorCalibrations();
  //debugMotorSpeedCalibration();
  //debugChart2();
  //unrecognizedCMD();
  debugLoopTime();
  Serial.println();

};


void ReadIMU() {
  my3IMU.getYawPitchRoll(ypr);
  altimeter = my3IMU.getBaroAlt();
}

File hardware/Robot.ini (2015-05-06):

[profile]
layer_height = 0.1
wall_thickness = 0.5
retraction_enable = True
solid_layer_thickness = 0.5
fill_density = 30
nozzle_size = 0.4
print_speed = 100
print_temperature = 220
print_temperature2 = 0
print_temperature3 = 0
print_temperature4 = 0
print_bed_temperature = 70
support = Everywhere
platform_adhesion = None
support_dual_extrusion = Both
wipe_tower = False
wipe_tower_volume = 15
ooze_shield = False
filament_diameter = 2.85
filament_diameter2 = 0
filament_diameter3 = 0
filament_diameter4 = 0
filament_flow = 100.0
retraction_speed = 40.0
retraction_amount = 4.5
retraction_dual_amount = 16.5
retraction_min_travel = 1.5
retraction_combing = True
retraction_minimal_extrusion = 0.02
retraction_hop = 0.0
bottom_thickness = 0.3
layer0_width_factor = 100
object_sink = 0.0
overlap_dual = 0.15
travel_speed = 150.0
bottom_layer_speed = 20
infill_speed = 0.0
inset0_speed = 0.0
insetx_speed = 0.0
cool_min_layer_time = 5
fan_enabled = True
skirt_line_count = 1
skirt_gap = 3.0
skirt_minimal_length = 150.0
fan_full_height = 5.0
fan_speed = 100
fan_speed_max = 100
cool_min_feedrate = 10
cool_head_lift = False
solid_top = True
solid_bottom = True
fill_overlap = 15
support_type = Lines
support_angle = 60
support_fill_rate = 10
support_xy_distance = 0.7
support_z_distance = 0.2
spiralize = False
simple_mode = False
brim_line_count = 20
raft_margin = 5.0
raft_line_spacing = 3.0
raft_base_thickness = 0.3
raft_base_linewidth = 1.0
raft_interface_thickness = 0.27
raft_interface_linewidth = 0.4
raft_airgap = 0.22
raft_surface_layers = 2
fix_horrible_union_all_type_a = True
fix_horrible_union_all_type_b = False
fix_horrible_use_open_bits = False
fix_horrible_extensive_stitching = False
plugin_config = 
object_center_x = -1
object_center_y = -1

[alterations]
start.gcode = ;Sliced at: {day} {date} {time}
	;Basic settings: Layer height: {layer_height} Walls: {wall_thickness} Fill: {fill_density}
	;Print time: {print_time}
	;Filament used: {filament_amount}m {filament_weight}g
	;Filament cost: {filament_cost}
	;M190 S{print_bed_temperature} ;Uncomment to add your own bed temperature line
	;M109 S{print_temperature} ;Uncomment to add your own temperature line
	G21        ;metric values
	G90        ;absolute positioning
	M82        ;set extruder to absolute mode
	M107       ;start with the fan off
	G28 X0 Y0  ;move X/Y to min endstops
	G28 Z0     ;move Z to min endstops
	G1 Z15.0 F{travel_speed} ;move the platform down 15mm
	G92 E0                  ;zero the extruded length
	G1 F200 E3              ;extrude 3mm of feed stock
	G92 E0                  ;zero the extruded length again
	G1 F{travel_speed}
	;Put printing message on LCD screen
	M117 Printing...
end.gcode = ;End GCode
	M104 S0                     ;extruder heater off
	M140 S0                     ;heated bed heater off (if you have it)
	G91                                    ;relative positioning
	G1 E-1 F300                            ;retract the filament a bit before lifting the nozzle, to release some of the pressure
	G1 Z+0.5 E-5 X-20 Y-20 F{travel_speed} ;move Z up a bit and retract filament even more
	G28 X0 Y0                              ;move X/Y to min endstops, so the head is out of the way
	M84                         ;steppers off
	G90                         ;absolute positioning
	;{profile_string}
start2.gcode = ;Sliced at: {day} {date} {time}
	;Basic settings: Layer height: {layer_height} Walls: {wall_thickness} Fill: {fill_density}
	;Print time: {print_time}
	;Filament used: {filament_amount}m {filament_weight}g
	;Filament cost: {filament_cost}
	;M190 S{print_bed_temperature} ;Uncomment to add your own bed temperature line
	;M104 S{print_temperature} ;Uncomment to add your own temperature line
	;M109 T1 S{print_temperature2} ;Uncomment to add your own temperature line
	;M109 T0 S{print_temperature} ;Uncomment to add your own temperature line
	G21        ;metric values
	G90        ;absolute positioning
	M107       ;start with the fan off
	G28 X0 Y0  ;move X/Y to min endstops
	G28 Z0     ;move Z to min endstops
	G1 Z15.0 F{travel_speed} ;move the platform down 15mm
	T1                      ;Switch to the 2nd extruder
	G92 E0                  ;zero the extruded length
	G1 F200 E10             ;extrude 10mm of feed stock
	G92 E0                  ;zero the extruded length again
	G1 F200 E-{retraction_dual_amount}
	T0                      ;Switch to the first extruder
	G92 E0                  ;zero the extruded length
	G1 F200 E10             ;extrude 10mm of feed stock
	G92 E0                  ;zero the extruded length again
	G1 F{travel_speed}
	;Put printing message on LCD screen
	M117 Printing...
end2.gcode = ;End GCode
	M104 T0 S0                     ;extruder heater off
	M104 T1 S0                     ;extruder heater off
	M140 S0                     ;heated bed heater off (if you have it)
	G91                                    ;relative positioning
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

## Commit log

2014-11-03 First version
    [Log_file.xlsx, Telemetry_2014101172146.csv, Telemetry_2014101172511.csv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]
2014-11-03 Revamping the serial communication
    Still issues with the conversion in the serial module
    [serial_communication.ino]
2014-11-04 Major version
    Changed:
    - serial communication
    - improved the arduino code
    - improved teh server code
    [Telemetry_2014101172146.csv, Telemetry_2014101172511.csv, Telemetry_201410117285.csv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]
2014-11-04 Bugfixes still issues on serial communication
    Need to develop a hash to accept data from Arduino
    [debug.ino, eeprom_store.ino, init.ino]
2014-11-05 First very stable configuration
    Still need to update the joystick and move routine
    [Telemetry_2014105222310.csv]
2014-11-05 Log file updated
    [Telemetry_201410602926.csv, Telemetry_20141060370.csv]
2014-11-07 First Stable version!
    Camera still not working properly
    [Telemetry_2014106215236.csv, Telemetry_2014106215449.csv, Telemetry_2014107183417.csv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]
2014-11-09 New version
    [Telemetry_2014107193628.csv, Telemetry_2014107194836.csv, Telemetry_2014109144845.csv]
2014-11-19 Updated Arduino code
    Added scaleThrottle command and found a very stable configuration
    [Telemetry_20141016151611.csv, Telemetry_20141019212532.csv]
2014-11-22 Improved control and rickshaw
    Improve the Arduino files for forward/backward movement and added
    Rickshaw library for future graph features.
2014-12-22 Updated PID parameters
2014-12-22 Most stable release so far!
    [Telemetry_20141122191532.csv, Telemetry_2014112220423.csv]
2014-12-27 SPO re-actvated
    Still need testing and feedback in the web console.
    [Telemetry_20141127163027.csv]
2015-05-06 Added hardware folder containig Openscad fiels for 3D printing
    [BlackRose.dxf, Letters.dxf, Log_file.xlsx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]
2015-05-06 UI updates
    [Telemetry_201546135141.csv, Telemetry_2015461418.csv]
2015-05-19 Updated Socket io library
2015-06-10 New version with new firmware
    [BlackRose.dxf, Letters.dxf, PowerRegulator.fzz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]
2015-06-10 Added libraries for Arduino
2015-06-13 Version 0.99 Still need to fix the transmission of PID parameters
    [BlackRose.dxf, Letters.dxf, Robot.scad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]
2015-06-14 Still need to fix PID parameter transfer
2015-06-17 Still CalibratedZeroAngledoes not get transferred
2015-07-05 Fixed the communication issues, now Bailey should receive and interpret commands correctly. Also added facility to debug, just request “serialMonitor”.
    [init.ino, serial_communication.ino]
2015-07-17 Updated telemetry logging
    [Robot.scad, RobotHead.scad, ServoHorn.scad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]
2015-08-01 Updated telemetry logging facility
    [RobotHead.scad, SupportNOservo.stl, Supportservo.stl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]
2015-08-01 Updated pitch
2016-03-20 Updated with stepper motor expansion
    [Robot.scad]
2016-03-20 Baseplate is now compatible with any motor bracket
    [Robot.scad]
2016-04-16 First release working with
    Need to integrate code for motors
2016-04-23 Camera working
2026-10-12 Rewrite balancing firmware so Bailey can actually balance
    The previous firmware could not balance: motor output was commented out,
    the angle and speed PIDs never received IMU/encoder input, the IMU was read
    every 100 ms, UserControl[1] indexed past a 1-element array, all
    TimedActions were built with zero intervals from an unloaded config, and
    TriggerAngleAggressive/anglePIDSampling commands overwrote other gains.
    The autotuner's fitness was always 0 (integer division) and its search
    space was all zeros; EEPROM settings were overwritten on every boot.
    New firmware:
    - fixed 200 Hz cascaded speed -> angle PID loop with derivative on
    measurement, clamped integrators, ramped speed setpoint and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
2026-10-12 Switch to steppers via FastAccelStepper and MPU-6050 complementary filter
    - Steppers are now the default. Step pulses come from FastAccelStepper 2.0.0
    (hardware timer, acceleration ramps) instead of a hand-written Timer2 ISR.
    On the Mega the STEP pins must be Timer 4 outputs (6, 7, 8).
    - Replace the unmaintained FreeIMU with the Electronic Cats MPU6050 library
    (maintained i2cdevlib) and a complementary filter. The angle PID's D term
    now uses the gyro rate directly. Any mounting orientation works via imuAxis
    (0/1/2 = X/Y/Z) and imuInvert. Settings layout version bumped to 3.
    - Retune default gains for both motor types with the new IMU model and
    speed tracking included in the score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
2026-10-12 Replace particle swarm autotuner with model identification
    The robot on stepper wheels is an inverted pendulum on a speed-controlled
    cart: pitch'' = (g/L)(pitch - offset) - accel/L. The new autotuner measures
    L and the IMU offset while balancing (~30 s): baseline score and gyro bias,
    then a small two-sine wobble on the pitch setpoint while fitting the model by
    least squares, then verification on the new gains and zero. L is estimated
    twice (g/p1 and -1/p3); disagreement, poor fit, implausible L, wrong signs or
    worse balance reject the result and restore the previous settings. Driving,
    falls, Motors 0 or large tilt errors abort and restore.
    Gains are now stored in physical units (gains.ino)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
2026-10-12 Rewrite the Raspberry Pi server and web UI; add a drive watchdog
    Server (server/, Node 20+): replaces the Node 5-era app (socket.io 1,
    serialport 2, node-opencv) with express 5, socket.io 4 and serialport 13.
    - Robot protocol in its own module, dispatching on the line tag
    - Serial link reconnects automatically (USB unplug, Arduino reset) and
    re-requests the headers when the robot reboots
    - Camera via rpicam-vid MJPEG (libcamera-vid fallback), only while watched;
    overlays drawn in the browser instead of re-encoding with OpenCV
    - Drive control repeats joystick commands while held and stops the robot
    if the controlling browser disconnects or stops updating
    - Telemetry CSV recording, Pi st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
2026-10-13 Add LQR balance controller, disturbance observer and Kalman filter
    LQR (bailey_FW/lqr.ino, default on steppers): the robot is modelled as an
    inverted pendulum on wheels whose acceleration is commanded directly. The
    discrete Riccati equation is solved on the Arduino with the structure-
    preserving doubling algorithm (matches SciPy to ~1e-5 in float32) for a
    reference length at boot or when a weight changes with the motors off, and
    the gain is rescaled to the measured pendulum length by dynamic similarity,
    so autotune can apply it while balancing. Weights are "how far each quantity
    may stray" (lqrMax*). Driving moves a speed/position reference.
    Disturbance observer: estimates the angle the rob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
2026-10-13 Port the firmware to the ESP32-S3 (Waveshare ESP32-S3-Pico)
    The board is picked at compile time: ARDUINO_ARCH_ESP32 selects the ESP32-S3
    configuration, otherwise the Mega 2560 one.
    ESP32-S3:
    - pins on GPIO 11-17 (STEP/DIR 11-14, ENABLE 17, I2C 15/16), chosen to be
    free on any ESP32-S3 with quad PSRAM (avoids boot-mode, USB, flash/PSRAM
    and the Pico's RGB LED pins)
    - 500 Hz balance loop (hardware FPU); the LQR is discretised for it
    - EEPROM emulated in flash: EEPROM.begin() at boot, commit() after writes
    - Wire.begin(SDA, SCL) on the configured pins
    - DC motors stay Mega-only (compile error otherwise)
    SYS line now reports Board and ControlPeriodUs; the web UI shows the board
    and judges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
2026-10-13 Add MPC controller (ESP32-S3) and make fast driving safe for LQR and MPC
    MPC (bailey_FW/mpc.ino, "SCMD controller 2", ESP32-S3 only): same model,
    state and disturbance observer as the LQR, planning 1.2 s ahead (40 x 30 ms)
    around the steppers' acceleration and speed limits. Pre-stabilised: the plan
    is the LQR plus corrections, with the LQR's Riccati solution as terminal
    cost, so the cost is exact and without limits in sight it is exactly the
    LQR. This also keeps the long horizon well conditioned in float32 (a plain
    condensed MPC of the unstable robot 1.5 s ahead diverged in tests). Limits
    are stiff penalties minimised with FISTA; each gradient is one forward and
    one adjoint pass.
    In the sim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
2026-10-14 Drive with a PS4/PS5 controller over Bluetooth
    The Pi reads the paired controller straight from /dev/input (hid-playstation /
    hid-sony), no native modules. Left stick drives (50 %, R1 for 100 %), right
    stick steers, X motors on, O or PS motors off.
    Safety: the motion sensors report continuously while connected, so 0.5 s of
    silence counts as lost and the robot stops, instead of waiting up to 20 s for
    Bluetooth to drop the link. After a loss the sticks must be moved again.
    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
2026-10-14 Run the firmware simulator in the browser
    The simulator (real firmware + robot model) now also builds to WebAssembly
    (bailey_FW/test/build_wasm.sh, ESP32-S3 stepper configuration), and
    bailey_FW/test/web/index.html is an interactive page around it: side view of
    the robot, joystick, pushes, payload off-centre, centre of mass height, IMU
    noise, LQR/MPC/PID, autotune, charts, top view and the serial port.
    sim.cpp: the live mode and main() are left out of the WebAssembly build.
    Claude-Session: https://claude.ai/code/session_01Nm8V6Wa2JnRS9Ffra67Pjc
2026-10-14 Remove the old server and init.d script
    server/app, server/wwwroot (socket.io 1, serialport 2, node-opencv) and
    install/robotserver are replaced by server/src, server/public and the systemd
    service. install.sh still removes an installed /etc/init.d/robotserver.
    They remain in the git history.
    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
2026-10-14 Firmware 3.0: Eigen for the matrix maths, TinyMPC for MPC, ESP32-S3 only
    - lqr.ino: the Riccati solver (structure-preserving doubling) now uses Eigen
    (fixed-size 4x4, LU solves) instead of hand-written matrix code, and the
    model is discretised exactly (cosh/sinh). Still matches SciPy to 1e-4.
    - mpc.ino: MPC is solved by TinyMPC (vendored in src/tinympc, MIT, float,
    three small documented changes), every 30 ms on the ESP32-S3's second core;
    the 500 Hz loop follows the latest plan with the LQR gain and falls back to
    plain LQR when there is none.
    - ESP32-S3 and steppers only: the Mega can't build Eigen or TinyMPC (no C++
    standard library). Mega and DC motor code, settings and simula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
2026-10-14 Check every hand-written part against libraries; fix the robot model MuJoCo found
    Physics: the simulator now uses the Lagrange equations of a body on wheels
    turned by motors bolted to it, checked against MuJoCo (test/mujoco_check.py,
    within 0.02 deg). The old cart-pole model had the robot falling 55 % too fast,
    and the old autotuner would have rejected every run on the real robot (its
    two length estimates differ by ~38 % there, limit 25 %).
    - Firmware model: pitch'' = (g pitch - kappa a) / L. kappa (pendulumCoupling,
    ~1.4 for Bailey) in the LQR/MPC model, observer and PID scaling; the
    autotuner measures L and kappa, rejects implausible kappa, and adds an
    independent acceleration wobbl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
2026-10-14 Watchdog, settings in NVS, serial checksums, uPlot charts, WebRTC video
    Firmware:
    - Hardware watchdog (ESP32 task watchdog, 300 ms) on the loop task, armed
    after setup; watchdog, brownout and crash restarts are reported at boot.
    - Settings stored with the ESP32 Preferences library (NVS: wear-levelled,
    safe against power loss mid-save) instead of emulated EEPROM; magic,
    layout version and checksum checks kept.
    - CRC-8 "*HH" on every serial line both ways (output through a small Print
    wrapper); bad lines are rejected and counted, lines without one accepted.
    Server and UI:
    - Checksums added to everything sent, checked on everything received.
    - Charts with uPlot 1.6.32 (served from node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
2026-10-14 Simulator: optional MuJoCo plant (sim_mujoco)
    Adds a 3D MuJoCo model of the robot (free-joint body, two wheels rolling
    with friction, steppers as stiff position servos) as an alternative to the
    built-in equations, built by build_mujoco.sh when MuJoCo is installed, and
    a run_tests.sh section that runs the LQR/MPC scenarios and autotune on it.
    Work in progress: the last full run_tests.sh run reported a failure that
    has not been identified yet.
    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
2026-10-14 MuJoCo simulator: valid inertias at any size, README
    - Body roll/yaw and wheel inertias in proportion to the pitch inertia, so
    MuJoCo accepts the model for every robot size (the scaling scenario hit
    'inertia must satisfy A + B >= C').
    - run_tests.sh: the scaling scenario stays on the built-in plant only; its
    7 cm robot doesn't balance on MuJoCo's contact model.
    - README: sim_mujoco, and A4988 logic needs VDD at 3.3 V for 3.3 V signals.
    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
2026-10-20 Hardware: Raspberry Pi 4B case (link and mounting notes)
    The case is i-BoxIt's MakerWorld design under the Standard Digital File
    License, so the repository links to it instead of including the file.
    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
2026-10-26 Bailey 2026: datasheet, simulator and defaults for the new robot
    - hardware/README.md: datasheet of the Fusion 360 Bailey (PLA frame from
    the STEP export, 17HD34008 motors, TMC2209/2226, 65 mm wheels, 3S pack,
    electronics, mass budget, L 0.24 m and kappa 1.56) and model fixes to
    make before printing.
    - Simulator robot (Plant) is the new Bailey; setLength keeps its
    proportions on 65 mm wheels. Firmware defaults: wheelDiameter 65,
    pendulumLength 0.24, pendulumCoupling 1.56, lqrAccelLimit 4.5.
    - Autotune: VERIFY scores after 4 s (9 s phase). A tall robot takes ~3 s
    to calm down after MEASURE's wobble, so it rejected correct results.
    - MuJoCo: the stepper servo is as stiff as the tim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
2026-10-26 Datasheet: correct the body's pitch inertia (11.5 g·m²)
    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
2026-10-31 Hardware: snap-in holders for the small boards (OpenSCAD)
    pcb_clip holds boards without mounting holes (the buck converter) on
    corner pads under flexible hooks; pcb_posts holds boards with holes
    (ESP32-S3-Pico) on posts with pilot holes. Both screw to a shelf (M3,
    countersunk) or take a cable tie.
    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
2026-10-31 Hardware: socket for the ESP32-S3-Pico (no mounting holes)
    The ESP32-S3-Pico has no holes, unlike the Raspberry Pi Pico the old
    preset assumed. pico_socket holds two 1 x 20 female header strips the
    board plugs into; with stacking headers the wires plug onto the tails.
    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
2026-10-31 ESP32 socket: open pointed arches in the end legs
    The end legs are open arches for the wires and to save material. They
    are equilateral, so they print without support, and start above the base
    so the screw tabs and a sill stay solid.
    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
2026-11-01 Hardware: universal board clamp and an adjustable IMU bracket
    board_clamp holds any board from its size: one edge in a groove, the
    other under a bar with two M3 screws, gaps for connectors at the edges,
    open underneath for pins and wires. Presets for the ESP32-S3-Pico, the
    TMC drivers and the buck converter.
    imu_mount puts the IMU chip on the axle line: vertical slots for height,
    slots under the board for fore-aft, and sight notches at the chip's
    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
2026-11-01 Web simulator: defaults for the new Bailey (L 0.24 m, IMU near the axle, 33 s autotune)
    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
